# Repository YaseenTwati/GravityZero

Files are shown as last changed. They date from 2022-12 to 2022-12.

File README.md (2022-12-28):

# GravityZero

GravityZero is an Open Source STM32G473-based development board with two USB ports (Native & CH340 Serial), and access to nearly all the IO ports through the headers. alongside an onboard "NeoPixel" RGB LED.

More can be learned about it in my [Write Up Here](https://yaseen.ly/stm32g473-development-board-gravityzero/).

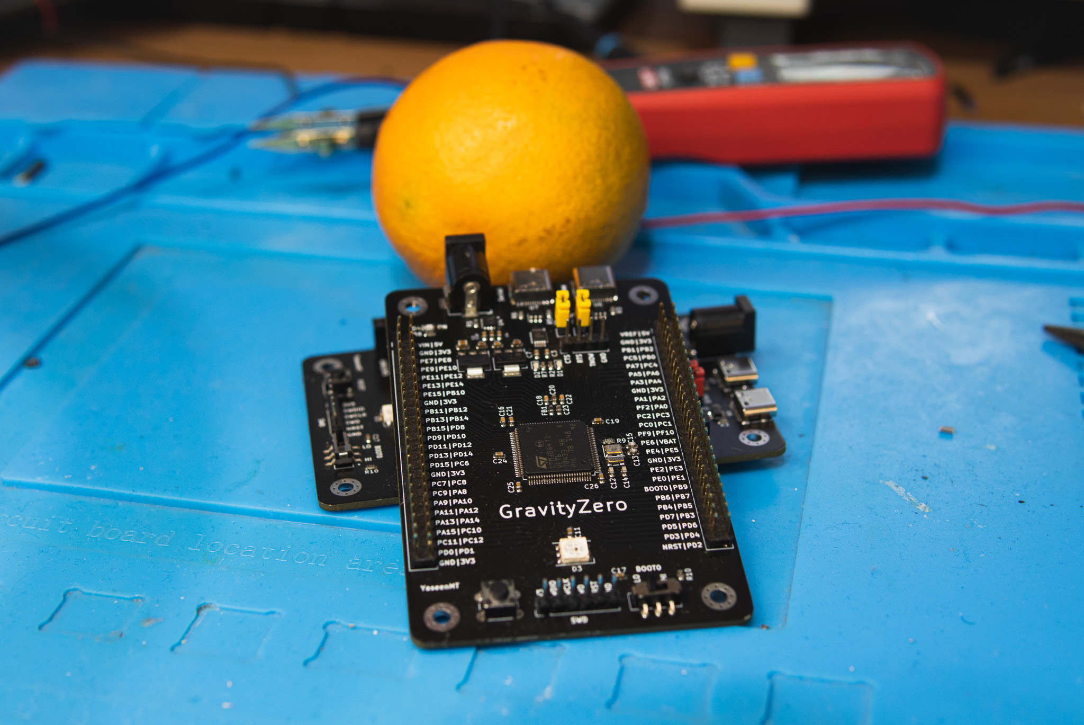
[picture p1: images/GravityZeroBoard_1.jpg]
Gravity Zero PCB


### Should you build one ?
Most probably not no, the microcontroller isn't cheap ( at the time of writing ), the pcb is 4 layer pcb which can most likely be reduced down to two, and there plenety of cheaper options out there.
This was designed for the experience & fun, which again you can learn more about in my write up.

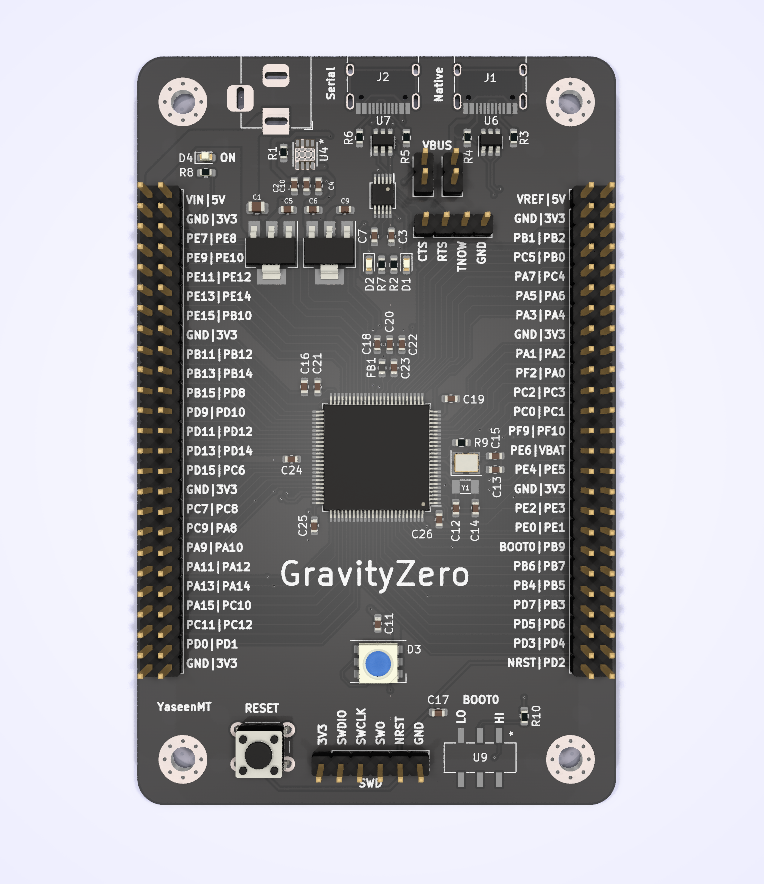
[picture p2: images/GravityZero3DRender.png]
Gravity Zero PCB


---
### License 
<br />This work is licensed under a <a rel="license" href="http://creativecommons.org/licenses/by-sa/4.0/">Creative Commons Attribution-ShareAlike 4.0 International License</a>.

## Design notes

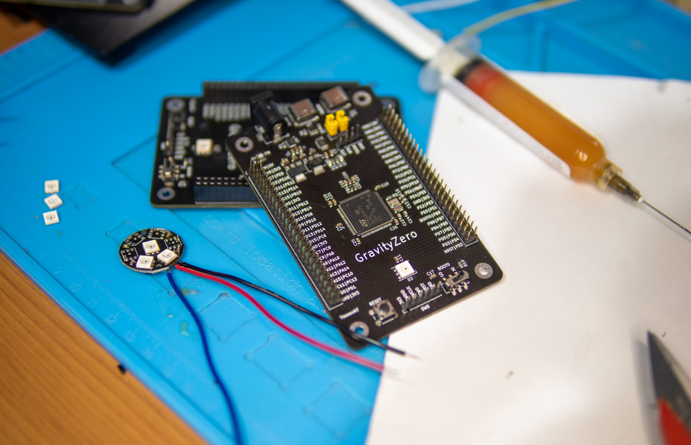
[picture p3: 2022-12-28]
images/GravityZeroBoard_2.jpg

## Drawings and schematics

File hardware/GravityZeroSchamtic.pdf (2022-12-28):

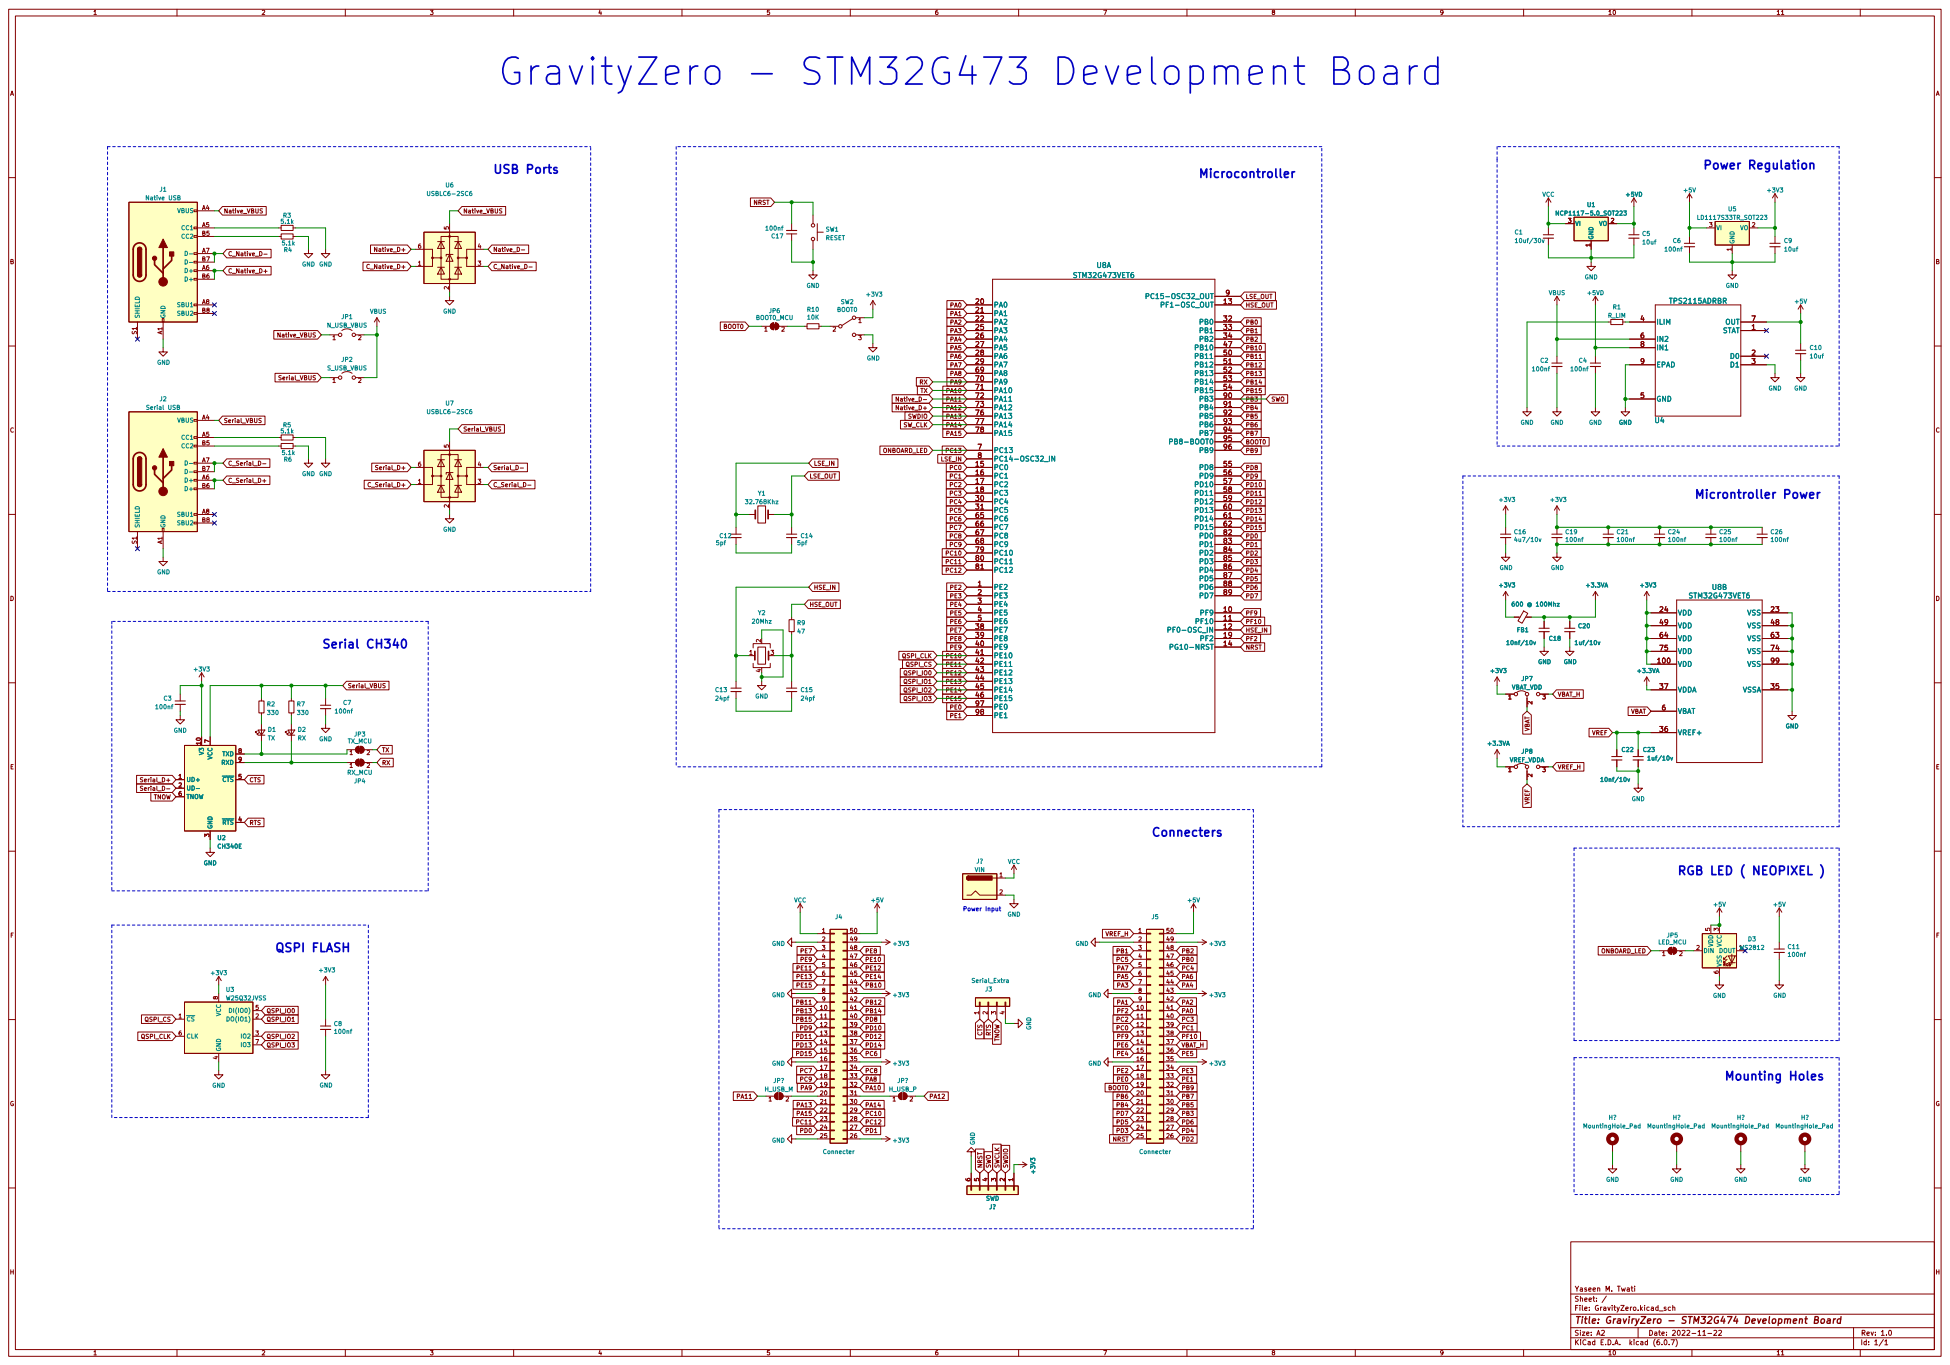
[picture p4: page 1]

3 ~{RTS} 4 ~{CTS} 5 TNOW 6 VCC

File: GravityZero.kicad_sch Sheet: / Yaseen M. Twati

Id: 1/1 Title: GraviryZero - STM32G474 Development Board

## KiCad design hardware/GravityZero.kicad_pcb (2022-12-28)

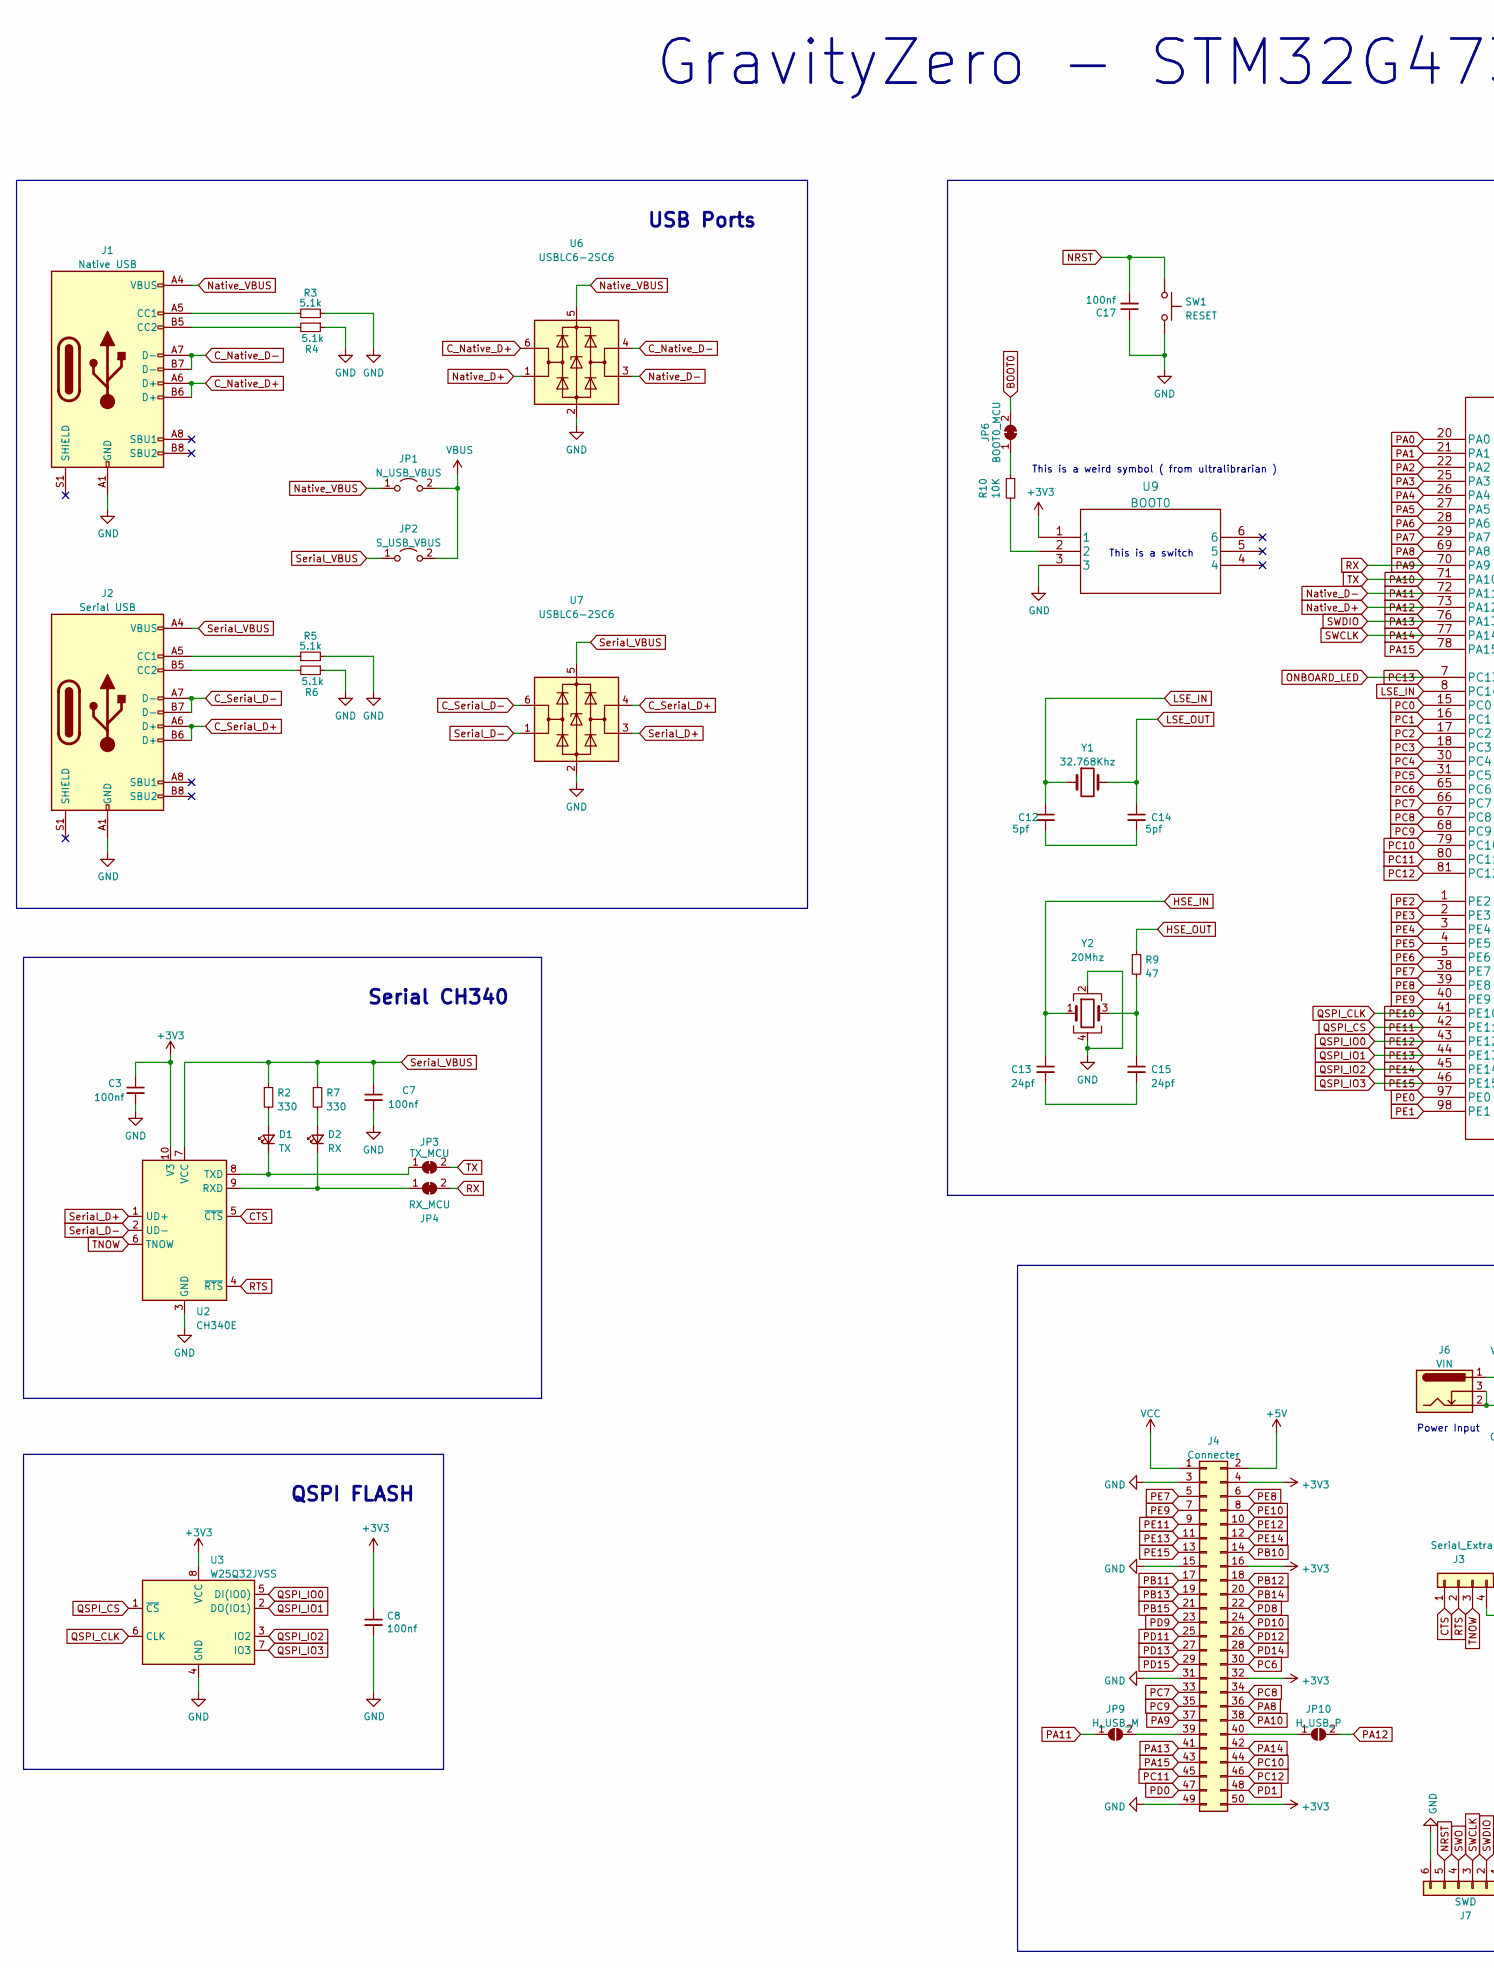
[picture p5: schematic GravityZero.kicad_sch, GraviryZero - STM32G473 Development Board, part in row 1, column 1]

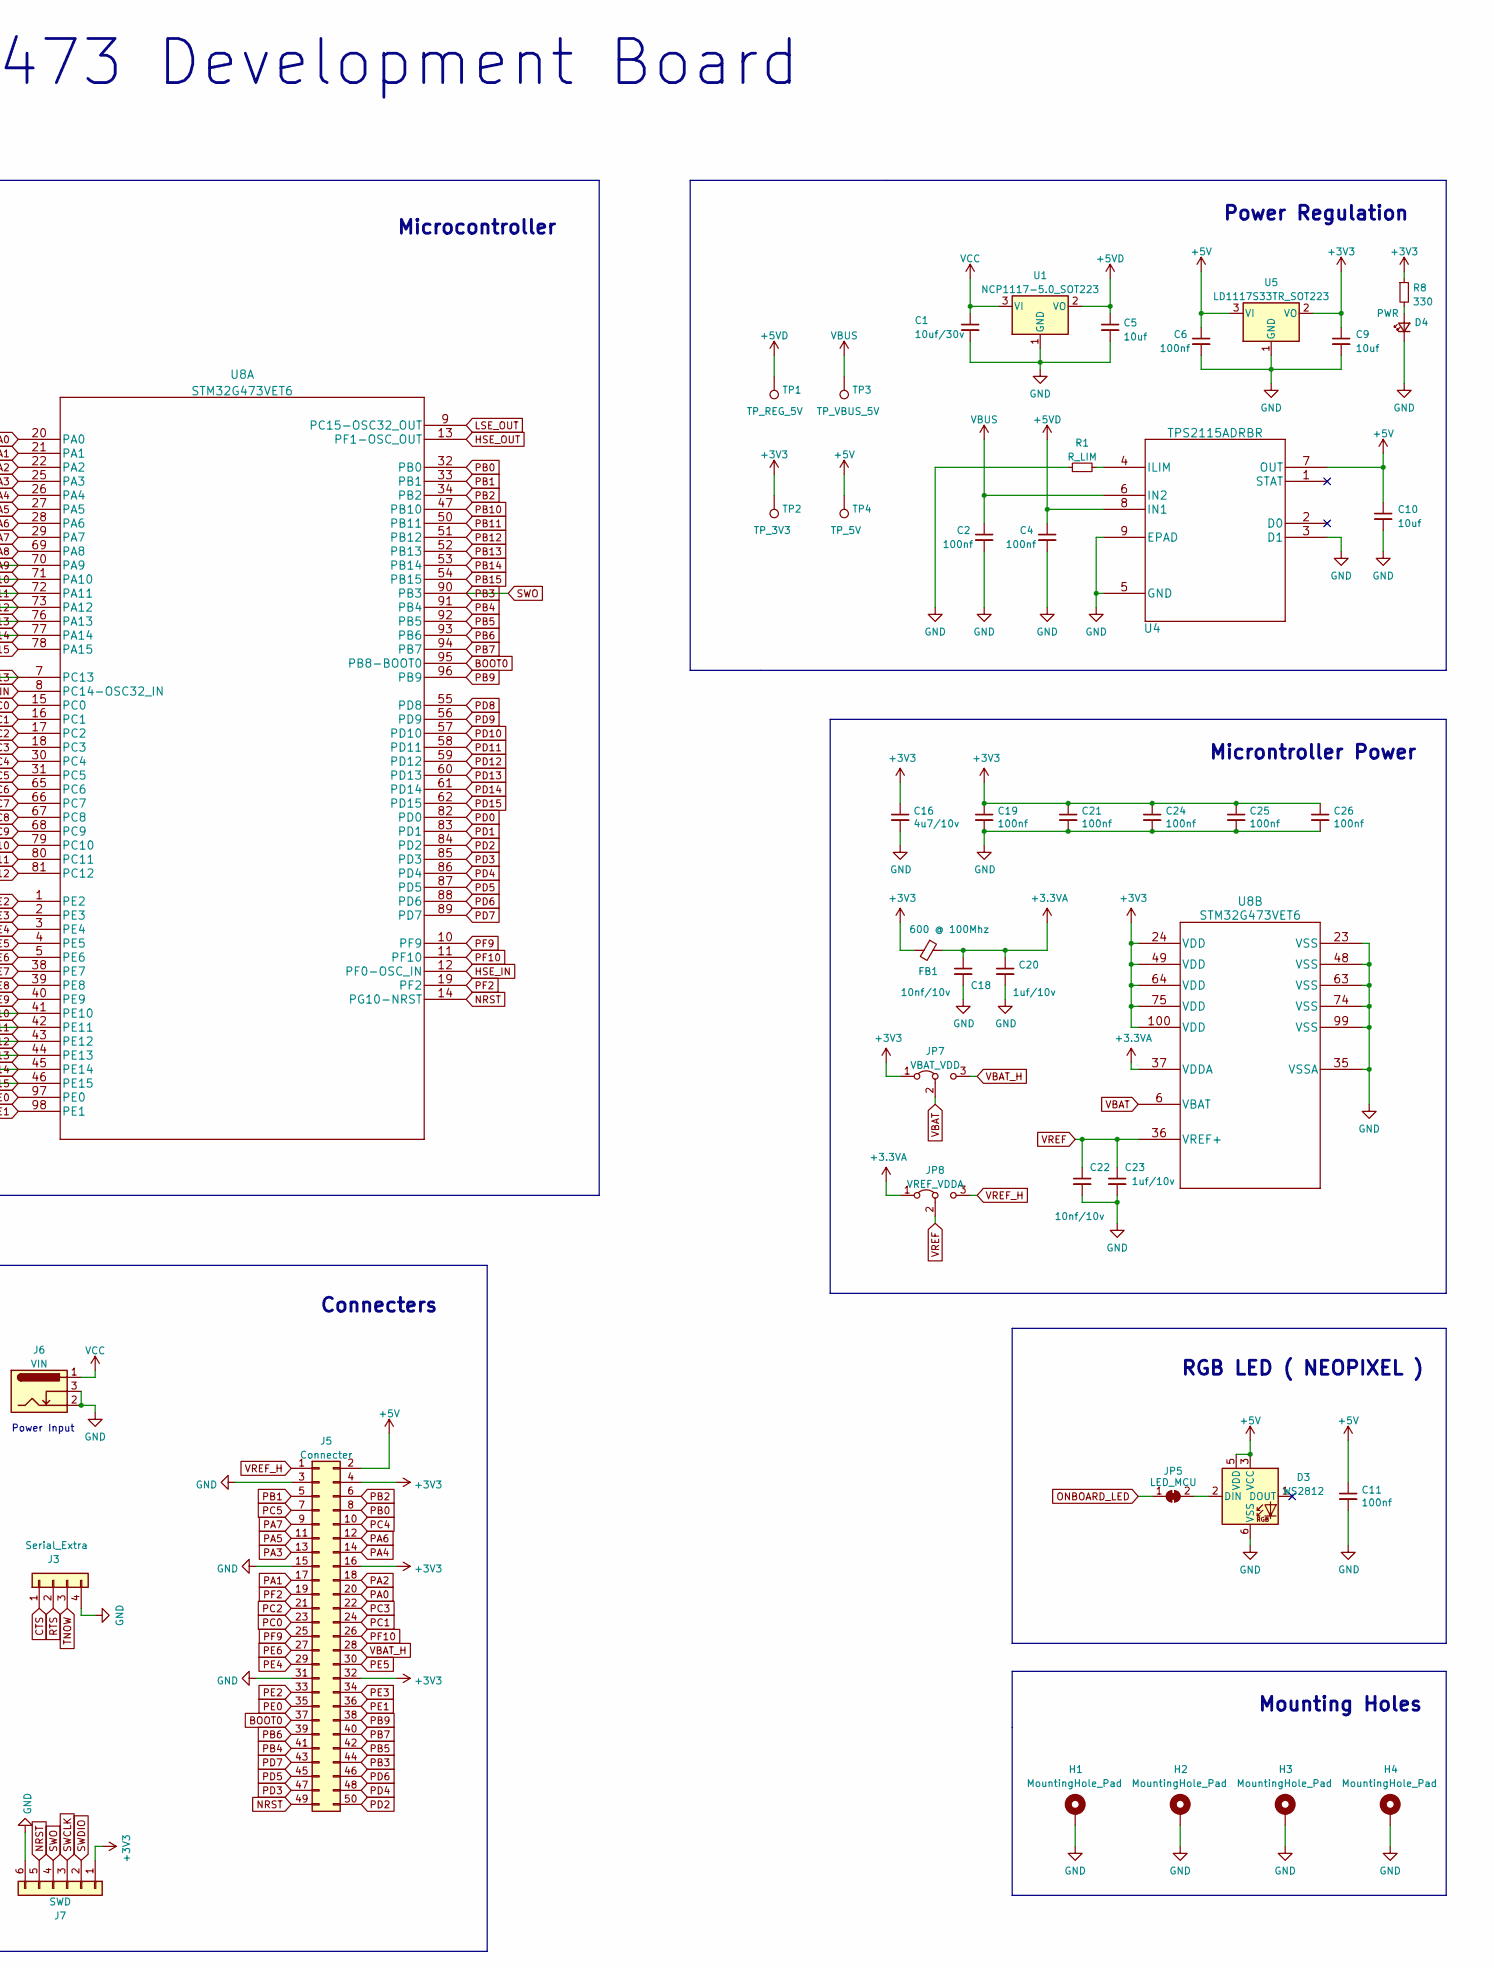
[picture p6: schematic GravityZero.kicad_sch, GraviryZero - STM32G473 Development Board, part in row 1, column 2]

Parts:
C1: 10uf/30v; C_0805_2012Metric
C2, C3, C4, C6, C7, C8, C11, C17, C19, C21, C24, C25, C26: 100nf; C_0603_1608Metric
C5, C9, C10: 10uf; C_0603_1608Metric
C12, C14: 5pf; C_0603_1608Metric
C13, C15: 24pf; C_0603_1608Metric
C16: 4u7/10v; C_0603_1608Metric
C18, C22: 10nf/10v; C_0603_1608Metric
C20, C23: 1uf/10v; C_0603_1608Metric
D1: TX; LED_0603_1608Metric
D2: RX; LED_0603_1608Metric
D3: WS2812; LED_WS2812_PLCC6_5.0x5.0mm_P1.6mm
D4: PWR; LED_0603_1608Metric
FB1: 600 @ 100Mhz; L_0603_1608Metric
H1, H2, H3, H4: MountingHole_Pad; MountingHole_3.2mm_M3_Pad_Via
J1: Native USB; USB_C_Receptacle_HRO_TYPE-C-31-M-12
J2: Serial USB; USB_C_Receptacle_HRO_TYPE-C-31-M-12
J3: Serial_Extra; PinHeader_1x04_P2.54mm_Vertical
J4, J5: Connecter; PinHeader_2x25_P2.54mm_Vertical
J6: VIN; BarrelJack_Horizontal
J7: SWD; PinHeader_1x06_P2.54mm_Vertical
JP1: N_USB_VBUS; PinHeader_1x02_P2.54mm_Vertical
JP2: S_USB_VBUS; PinHeader_1x02_P2.54mm_Vertical
JP3: TX_MCU; SolderJumper-2_P1.3mm_Open_TrianglePad1.0x1.5mm
JP4: RX_MCU; SolderJumper-2_P1.3mm_Open_TrianglePad1.0x1.5mm
JP5: LED_MCU; SolderJumper-2_P1.3mm_Open_TrianglePad1.0x1.5mm
JP6: BOOT0_MCU; SolderJumper-2_P1.3mm_Open_TrianglePad1.0x1.5mm
JP7: VBAT_VDD; SolderJumper-3_P2.0mm_Open_TrianglePad1.0x1.5mm
JP8: VREF_VDDA; SolderJumper-3_P2.0mm_Open_TrianglePad1.0x1.5mm
JP9: H_USB_M; SolderJumper-2_P1.3mm_Open_TrianglePad1.0x1.5mm
JP10: H_USB_P; SolderJumper-2_P1.3mm_Open_TrianglePad1.0x1.5mm
R1: R_LIM; R_0603_1608Metric
R2, R7, R8: 330; R_0603_1608Metric
R3, R4, R5, R6: 5.1k; R_0603_1608Metric
R9: 47; R_0603_1608Metric
R10: 10K; R_0603_1608Metric
SW1: RESET; SW_PUSH_6mm
TP1: TP_REG_5V; TestPoint_Pad_D1.0mm
TP2: TP_3V3; TestPoint_Pad_D1.0mm
TP3: TP_VBUS_5V; TestPoint_Pad_D1.0mm
TP4: TP_5V; TestPoint_Pad_D1.0mm
U1: NCP1117-5.0_SOT223; SOT-223-3_TabPin2
U2: CH340E; MSOP-10_3x3mm_P0.5mm
U3: W25Q32JVSS; SOIC-8_5.23x5.23mm_P1.27mm
U4: TPS2115ADRBR
U5: LD1117S33TR_SOT223; SOT-223-3_TabPin2
U6, U7: USBLC6-2SC6; SOT-23-6
U8: STM32G473VET6; LQFP-100_14x14mm_P0.5mm
U9: BOOT0; SS-3235S-L2
Y1: 32.768Khz; Crystal_SMD_3215-2Pin_3.2x1.5mm
Y2: 20Mhz; Crystal_SMD_3225-4Pin_3.2x2.5mm

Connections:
+3.3VA: C18.1, C20.1, FB1.1, JP8.1 (A), U8.37 (VDDA)
+3V3: C3.1, C8.1, C9.1, C16.1, C19.1, C21.1, C24.1, C25.1, C26.1, FB1.2, J4.4, J4.16, J4.32, J4.50, J5.4, J5.16, J5.32, J7.1, JP7.1 (A), R8.1, TP2.1, U2.10 (V3), U3.8 (VCC), U5.2 (VO), U8.24 (VDD), U8.49 (VDD), U8.64 (VDD), U8.75 (VDD), U8.100 (VDD), U9.1
+5V: C6.1, C10.1, C11.1, D3.3 (VCC), D3.5 (VDD), J4.2, J5.2, TP4.1, U4.7 (OUT), U5.3 (VI)
+5VD: C4.1, C5.1, TP1.1, U1.2 (VO), U4.8 (IN1)
BOOT0: J5.37, JP6.2 (B), U8.95 (PB8-BOOT0); also elsewhere on the board
CTS: J3.1, U2.5 (~CTS)
C_Native_D+: J1.A6 (D+), J1.B6 (D+), U6.6 (I/O1)
C_Native_D-: J1.A7 (D-), J1.B7 (D-), U6.4 (I/O2)
C_Serial_D+: J2.A6 (D+), J2.B6 (D+), U7.4 (I/O2)
C_Serial_D-: J2.A7 (D-), J2.B7 (D-), U7.6 (I/O1)
GND: C1.2, C2.2, C3.2, C4.2, C5.2, C6.2, C7.2, C8.2, C9.2, C10.2, C11.2, C16.2, C17.1, C18.2, C19.2, C20.2, C21.2, C22.2, C23.2, C24.2, C25.2, C26.2, D3.6 (VSS), D4.1 (K), H1.1, H2.1, H3.1, H4.1, J1.A1 (GND), J1.A12 (GND), J1.B1 (GND), J1.B12 (GND), J2.A1 (GND), J2.A12 (GND), J2.B1 (GND), J2.B12 (GND), J3.4, J4.3, J4.15, J4.31, J4.49, J5.3, J5.15, J5.31, J6.2, J6.3, J7.6, R1.1, R3.2, R4.1, R5.2, R6.1, SW1.2, U1.1 (GND), U2.3 (GND), U3.4 (GND), U4.3 (D1), U4.5 (GND), U4.9 (EPAD), U5.1 (GND), U6.2 (GND), U7.2 (GND), U8.23 (VSS), U8.35 (VSSA), U8.48 (VSS), U8.63 (VSS), U8.74 (VSS), U8.99 (VSS), U9.3, Y2.2, Y2.4
HSE_IN: C13.1, U8.12 (PF0-OSC_IN), Y2.1
HSE_OUT: R9.1, U8.13 (PF1-OSC_OUT)
LSE_IN: C12.1, U8.8 (PC14-OSC32_IN), Y1.1
LSE_OUT: C14.1, U8.9 (PC15-OSC32_OUT), Y1.2
NRST: C17.2, J5.49, J7.5, SW1.1, U8.14 (PG10-NRST)
Native_D+: JP10.2 (B), U6.1 (I/O1), U8.73 (PA12)
Native_D-: JP9.1 (A), U6.3 (I/O2), U8.72 (PA11)
Native_VBUS: J1.A4 (VBUS), J1.A9 (VBUS), J1.B4 (VBUS), J1.B9 (VBUS), JP1.1 (A), U6.5 (VBUS)
unnamed: C12.2, C14.2
unnamed: C13.2, C15.2
unnamed: C15.1, R9.2, Y2.3
unnamed: D1.1 (K), JP3.1 (A), U2.8 (TXD)
unnamed: D1.2 (A), R2.2
unnamed: D2.1 (K), JP4.1 (A), U2.9 (RXD)
unnamed: D2.2 (A), R7.2
unnamed: D3.2 (DIN), JP5.2 (B)
unnamed: D4.2 (A), R8.2
unnamed: J1.A5 (CC1), R3.1
unnamed: J1.B5 (CC2), R4.2
unnamed: J2.A5 (CC1), R5.1
unnamed: J2.B5 (CC2), R6.2
unnamed: J4.39, JP9.2 (B)
unnamed: J4.40, JP10.1 (A)
unnamed 34: JP6.1 (A), R10.1; also elsewhere on the board
unnamed: R1.2, U4.4 (ILIM)
unnamed: R10.2, U9.2
ONBOARD_LED: JP5.1 (A), U8.7 (PC13)
PA0: J5.20, U8.20 (PA0)
PA1: J5.17, U8.21 (PA1)
PA2: J5.18, U8.22 (PA2)
PA3: J5.13, U8.25 (PA3)
PA4: J5.14, U8.26 (PA4)
PA5: J5.11, U8.27 (PA5)
PA6: J5.12, U8.28 (PA6)
PA7: J5.9, U8.29 (PA7)
PA8: J4.36, U8.69 (PA8)
PA9: J4.37, JP4.2 (B), U8.70 (PA9)
PA10: J4.38, JP3.2 (B), U8.71 (PA10)
PA13: J4.41, J7.2, U8.76 (PA13)
PA14: J4.42, J7.3, U8.77 (PA14)
PA15: J4.43, U8.78 (PA15)
PB0: J5.8, U8.32 (PB0)
PB1: J5.5, U8.33 (PB1)
PB2: J5.6, U8.34 (PB2)
PB3: J5.44, J7.4, U8.90 (PB3)
PB4: J5.41, U8.91 (PB4)
PB5: J5.42, U8.92 (PB5)
PB6: J5.39, U8.93 (PB6)
PB7: J5.40, U8.94 (PB7)
PB9: J5.38, U8.96 (PB9)
PB10: J4.14, U8.47 (PB10)
PB11: J4.17, U8.50 (PB11)
PB12: J4.18, U8.51 (PB12)
PB13: J4.19, U8.52 (PB13)
PB14: J4.20, U8.53 (PB14)
PB15: J4.21, U8.54 (PB15)
PC0: J5.23, U8.15 (PC0)
PC1: J5.24, U8.16 (PC1)
PC2: J5.21, U8.17 (PC2)
PC3: J5.22, U8.18 (PC3)
PC4: J5.10, U8.30 (PC4)
PC5: J5.7, U8.31 (PC5)
PC6: J4.30, U8.65 (PC6)
PC7: J4.33, U8.66 (PC7)
PC8: J4.34, U8.67 (PC8)
PC9: J4.35, U8.68 (PC9)
PC10: J4.44, U8.79 (PC10)
PC11: J4.45, U8.80 (PC11)
PC12: J4.46, U8.81 (PC12)
PD0: J4.47, U8.82 (PD0)
PD1: J4.48, U8.83 (PD1)
PD2: J5.50, U8.84 (PD2)
PD3: J5.47, U8.85 (PD3)
PD4: J5.48, U8.86 (PD4)
PD5: J5.45, U8.87 (PD5)
PD6: J5.46, U8.88 (PD6)
PD7: J5.43, U8.89 (PD7)
PD8: J4.22, U8.55 (PD8)
PD9: J4.23, U8.56 (PD9)
PD10: J4.24, U8.57 (PD10)
PD11: J4.25, U8.58 (PD11)
PD12: J4.26, U8.59 (PD12)
PD13: J4.27, U8.60 (PD13)
PD14: J4.28, U8.61 (PD14)
PD15: J4.29, U8.62 (PD15)
PE0: J5.35, U8.97 (PE0)
PE1: J5.36, U8.98 (PE1)
PE2: J5.33, U8.1 (PE2)
PE3: J5.34, U8.2 (PE3)
PE4: J5.29, U8.3 (PE4)
PE5: J5.30, U8.4 (PE5)
PE6: J5.27, U8.5 (PE6)
PE7: J4.5, U8.38 (PE7)
PE8: J4.6, U8.39 (PE8)
PE9: J4.7, U8.40 (PE9)
PE10: J4.8, U3.6 (CLK), U8.41 (PE10)
PE11: J4.9, U3.1 (~CS), U8.42 (PE11)
PE12: J4.10, U3.5 (DI(IO0)), U8.43 (PE12)
PE13: J4.11, U3.2 (DO(IO1)), U8.44 (PE13)
PE14: J4.12, U3.3 (IO2), U8.45 (PE14)
PE15: J4.13, U3.7 (IO3), U8.46 (PE15)
PF2: J5.19, U8.19 (PF2)
PF9: J5.25, U8.10 (PF9)
PF10: J5.26, U8.11 (PF10)
RTS: J3.2, U2.4 (~RTS)
Serial_D+: U2.1 (UD+), U7.3 (I/O2)
Serial_D-: U2.2 (UD-), U7.1 (I/O1)
Serial_VBUS: C7.1, J2.A4 (VBUS), J2.A9 (VBUS), J2.B4 (VBUS), J2.B9 (VBUS), JP2.1 (A), R2.1, R7.1, U2.7 (VCC), U7.5 (VBUS)
TNOW: J3.3, U2.6 (TNOW)
VBAT: JP7.2 (C), U8.6 (VBAT)
VBAT_H: J5.28, JP7.3 (B)
VBUS: C2.1, JP1.2 (B), JP2.2 (B), TP3.1, U4.6 (IN2)
VCC: C1.1, J4.1, J6.1, U1.3 (VI)
VREF: C22.1, C23.1, JP8.2 (C), U8.36 (VREF+)
VREF_H: J5.1, JP8.3 (B)

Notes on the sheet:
Microntroller Power
Power Input
GravityZero - STM32G473 Development Board
Microcontroller
QSPI FLASH
This is a weird symbol ( from ultralibrarian )
Serial CH340
USB Ports
Mounting Holes
RGB LED ( NEOPIXEL )
Connecters
Power Regulation
This is a switch

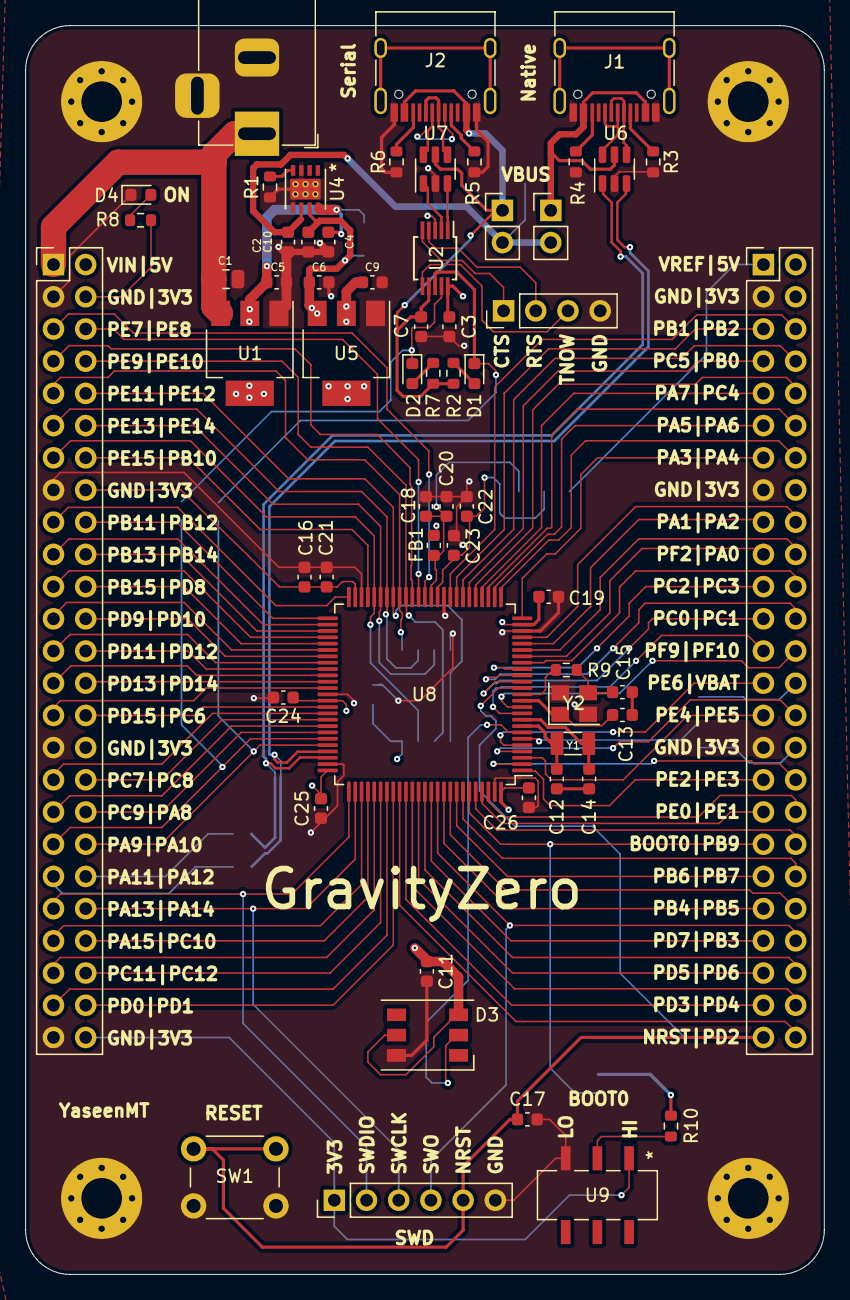
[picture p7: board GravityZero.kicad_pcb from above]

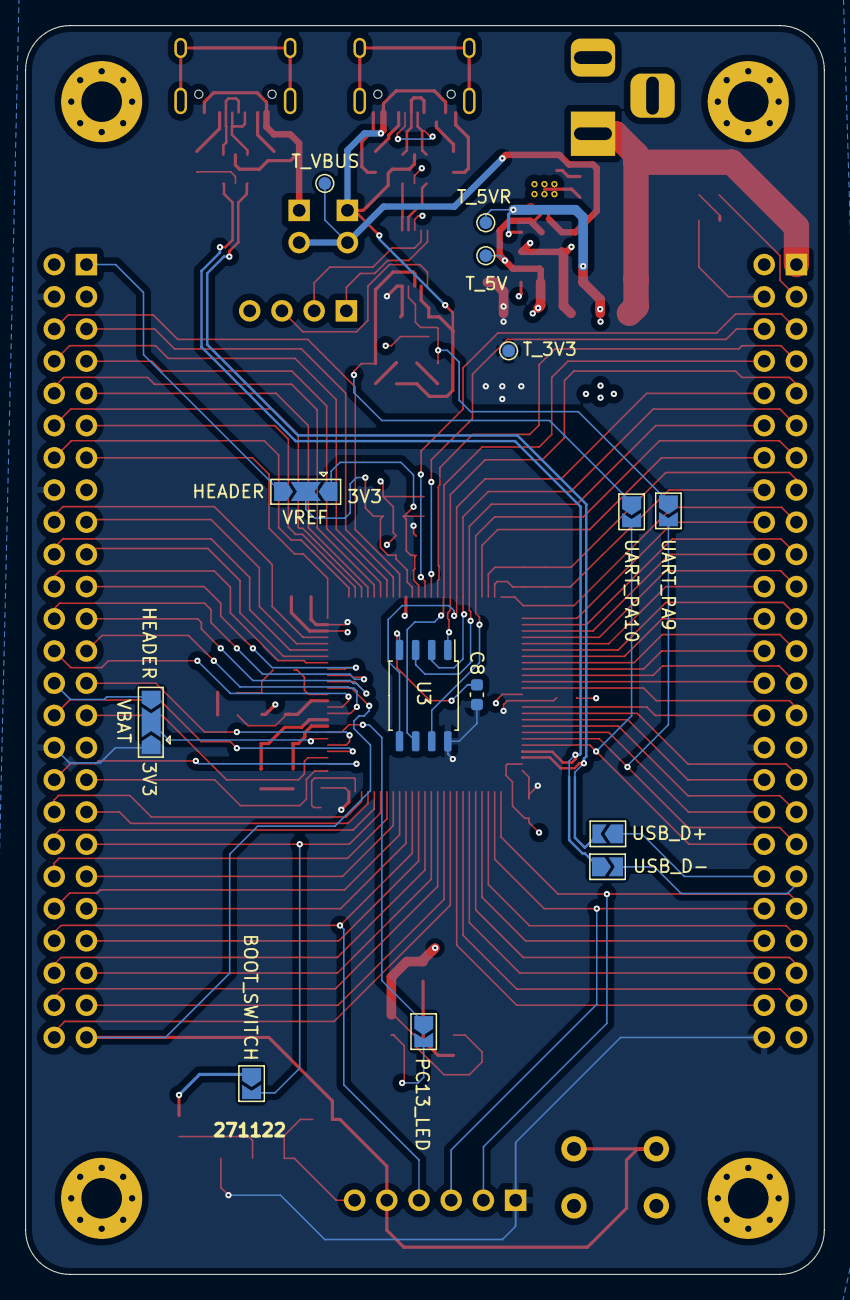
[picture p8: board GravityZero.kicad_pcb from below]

Board: 4 copper layers, 63.0 x 98.5 mm, 78 parts (14 on the bottom side), 126 nets.

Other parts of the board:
BOOT_SWITCH: BOOT0_MCU; SolderJumper-2_P1.3mm_Open_TrianglePad1.0x1.5mm

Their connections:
BOOT0: BOOT_SWITCH.2 (B); also elsewhere on the board
unnamed 34: BOOT_SWITCH.1 (A); also elsewhere on the board
